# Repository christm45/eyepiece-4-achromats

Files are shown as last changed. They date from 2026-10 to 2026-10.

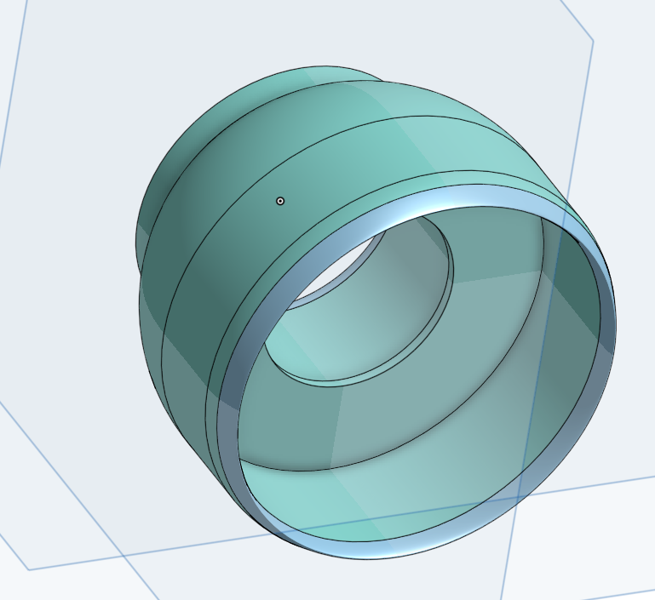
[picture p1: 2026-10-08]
top eye piece acceuil lentilles 30mm_3.png

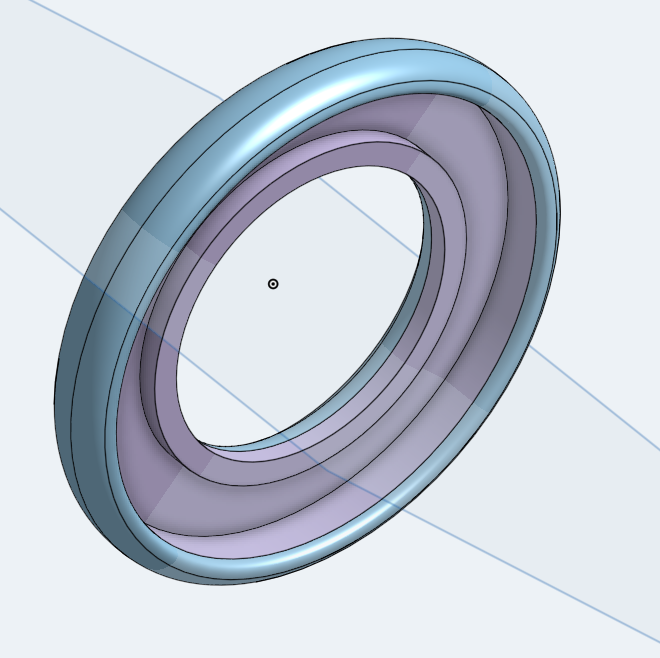
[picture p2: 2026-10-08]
top ring eye side 3d view.png

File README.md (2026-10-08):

# Oculaire 4 achromats / 4-achromat eyepiece

Oculaire de télescope imprimé en 3D, fait de 4 achromats de jumelles : une paire Ø40 mm côté focuser 2" et une paire Ø30 mm côté œil.
3D-printed telescope eyepiece built from 4 binocular achromats: a Ø40 mm pair on the 2" focuser side and a Ø30 mm pair on the eye side.

**Essayer en ligne / Try it online : https://christm45.github.io/eyepiece-4-achromats/**

Les pages 3D ont un bouton **FR / EN** (haut à droite de la vue). / The 3D pages have an **FR / EN** switch (top right of the view).

## Contenu / Contents

| Fichier / dossier | Rôle |
|---|---|
| `oculaire_3D.html` | Assemblage 3D (éclaté, coupe, rayons) + modèle optique du champ. Autonome : ouvrir dans un navigateur. |
| `banc_focale_3D.html`, `banc focale lentilles/` | Banc de mesure de la focale des achromats (STL, STEP, LISEZMOI, simulation 3D). |
| `stl_oculaire/` | Les 6 pièces imprimées de l'oculaire (STL). |
| `essais_oeilleton/` | Œilletons d'essai pour 24 / 20 / 17 / 14 mm de dégagement. |
| `build_oculaire.py` | Modèle CAO paramétrique (CadQuery). |
| `optics.js`, `test_optics.js` | Modèle optique paraxial (source unique de la page et des tests : `node test_optics.js`). |
| `mesure_focale.py` | Calcul de la focale à partir des lectures du banc. |
| `make_html.py`, `make_banc.py`, `mesh_export.py`, `export_stl.py`, `export_essais.py` | Régénération des pages, des maillages et des STL. |
| `vendor/` | three.js (licence MIT) intégré aux pages. |

## Précision : ce qui est mesuré, estimé, calculé

- **Lues sur les captures Onshape** (`*.png`) : Ø50,8 / Ø56 / Ø42,5 / Ø37 / profondeur 27 (base) ; Ø61 / Ø56,3 / Ø33 / Ø29 (coiffe) ; bague Ø50 / Ø44,3 / Ø32,5 / Ø28, hauteur 5,9.
- **Estimées, à ajuster** : épaisseurs des achromats (8 mm pour Ø40, 6 mm pour Ø30), longueur de la base, forme du dôme.
- **Focales : par défaut 160 / 110 mm = valeurs typiques de jumelles, PAS mesurées.** Mesurez les vôtres avec le banc, puis entrez-les dans la page : tous les chiffres se recalculent.
- **Modèle optique** : premier ordre, lentilles minces placées au milieu de leur épaisseur, ouvertures finies. Il donne la géométrie (vignettage, champ, dégagement, focale) mais **pas la netteté au bord** (astigmatisme, courbure de champ, coma, distorsion). Vérifié contre la formule de deux paires minces (F = F1·F2 / (F1 + F2 − d)).
- **Dégagement d'œil** : mesuré depuis la dernière surface de verre. **Plan de champ** : mesuré depuis la première surface de verre.
- Pupille de sortie prise à 4 mm et diaphragme de champ du fourreau 2" à Ø46 (valeurs nominales ; à adapter à votre fourreau).

Aucun résultat de ce dépôt n'a été validé sur le ciel : c'est un outil de conception, pas une garantie de performance.

## Licence / License

MIT : utilisation, copie, modification et partage libres (y compris commercial), en conservant la mention de copyright. Voir `LICENSE`. three.js (`vendor/`) reste sous sa propre licence MIT.
MIT: free to use, copy, modify and share (commercial use included), keeping the copyright notice. See `LICENSE`. three.js (`vendor/`) keeps its own MIT license.

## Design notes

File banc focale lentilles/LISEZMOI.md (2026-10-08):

# Banc de mesure de la focale des achromats

Pièces (STL, une impression chacune) : `1_rail_A`, `2_rail_B`, `3_chariot_lentille`, `4_chariot_ecran`, `5_support_source`.
`assemblage_banc.step` montre l'ensemble. Le rail fait 2 × 160 mm ; les deux moitiés s'emboîtent par une queue d'aronde (jeu 0,35 mm) :
graduation de 0 à 305 mm, un trait par mm (plus long tous les 5 et 10 mm), chiffres tous les 50 mm.

## Principe
Une source **lointaine** (au moins 2 m : fenêtre éloignée, LED au bout de la pièce, lampe) est imagée par la lentille sur un écran
(papier sulfurisé / calque) qui coulisse sur le rail. On lit où l'image est nette, puis :

    f = u·v / (u + v)

`u` = distance source → lentille au mètre ruban ; `v` = distance lentille → écran. Avec u = 3 m, sans correction l'erreur serait de 5 %
sur une focale de 160 mm : c'est pourquoi la formule est obligatoire.

## Montage
1. Imprimez les 5 pièces (chariots : posez-les sur leur face de glissement ouverte vers le bas avec supports, ou retournés ; vérifiez que le rail coulisse avant de l'utiliser, au besoin poncez ou changez `JEU`).
2. Emboîtez le rail B dans le rail A par la queue d'aronde. Posez le tout sur une table.
3. Chariot lentille : la lentille se pose dans le logement étagé **depuis l'avant (côté source)** ; elle s'appuie sur un épaulement :
   Ø50 → épaulement 1, Ø40 → épaulement 2, Ø30 → épaulement 3. Serrez-la par la tranche avec une vis **M3 en nylon** (2 trous M3 sur le dessus, à tarauder).
   Orientez l'achromat comme il l'était dans les jumelles (côté objet vers la source) ; la focale ne dépend pas du sens, mais l'image est plus nette ainsi.
4. Chariot écran : glissez une bande de papier sulfurisé dans la fente du haut (c'est le plan de mesure).
5. Support source (`5_support_source`) : la **LED 5 mm est sur l'axe optique** (z = 52 mm, même hauteur que la lentille ; elle était à 38 mm dans une version précédente). Insérez la LED **par l'arrière**, collerette contre l'épaulement (les fils sortent par la rainure du bas). Devant la pointe, dans la fente de 1,1 mm : un **masque** en papier alu (trou d'épingle ~0,5 mm percé à l'aiguille, ou petite croix). La sortie est évasée : la lumière diverge après le trou.
   Alimentation : 5 V USB + résistance ~150 Ω (LED blanche, ~12 mA), ou pile 3 V + ~47 Ω. Une LED nue (Ø5) marche aussi (image de ~0,3 mm à 3 m) mais le masque donne une mise au point plus précise.
   Posez le support sur la table, à 2 m ou plus de la lentille, face au rail, LED à la même hauteur que l'axe du chariot lentille. La page 3D simule la LED, le masque, le faisceau et la taille de l'image du masque sur l'écran.

## Lecture
Chaque chariot a une **fenêtre de lecture** de 10 × 23 mm au-dessus de la voie graduée, avec un **fil repère** de 0,8 mm : on lit le trait qui est sous le fil ; les chiffres sont gravés tous les 10 mm et visibles dans la fenêtre (traits tous les mm, plus longs à 5 et 10 mm). Regardez de dessus, à la verticale, pour éviter la parallaxe.
- Chariot lentille : le fil repère est 11,5 / 8,5 / 5,5 mm derrière la face arrière de la lentille (Ø50 / Ø40 / Ø30).
- Chariot écran : le fil repère est 8,0 mm derrière le plan du papier.
Notez la lecture du chariot lentille, déplacez l'écran jusqu'à l'image la plus nette (petit point lumineux), notez sa lecture, puis :

    python mesure_focale.py 40 60 225 3000 8

(Ø40, lectures 60 et 225, source à 3000 mm, épaisseur de la lentille 8 mm). Le script donne BFD, v et f.

## Précision et pièges
- Lecture à ±0,5 mm sur chaque trait : f à ±1 mm. Le plan principal d'un achromat épais est supposé au milieu de son épaisseur : jusqu'à ~2 mm d'écart possible.
- Pour une meilleure précision : mesurez **deux fois**, la lentille retournée, et prenez la moyenne.
- Un achromat de jumelle est corrigé pour une source lointaine et un faisceau étroit : travaillez à pleine ouverture mais cherchez l'image la plus petite, pas la plus lumineuse.
- Des focales jusqu'à ~280 mm tiennent sur le rail (305 mm). Au-delà, rallongez en ajoutant un segment.
- Pour une **paire** (les deux achromats face à face), mesurez-la montée comme dans l'oculaire (écart entre les lentilles = celui de l'oculaire) : sa focale est ≈ f/2.
- Les trois jeux et dimensions sont dans `build_banc.py` (`JEU`, `RAIL_SEG`, `STEPS`) si votre imprimante demande un autre réglage.

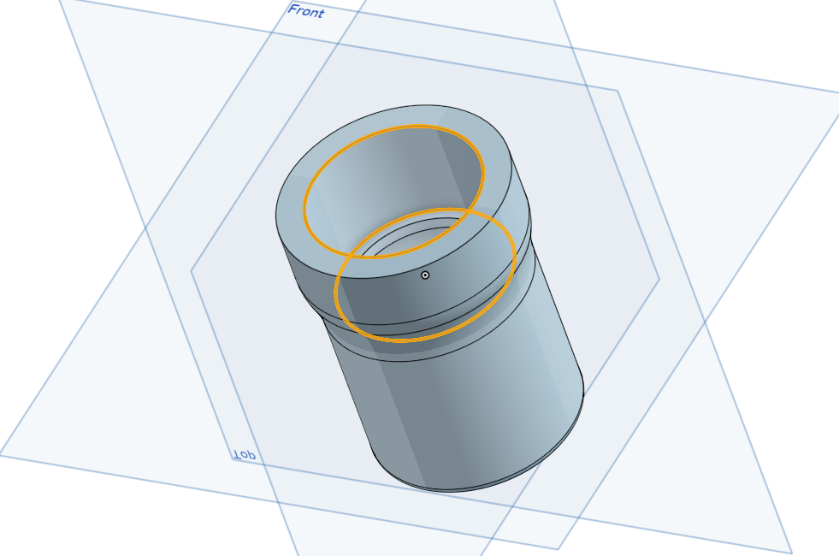
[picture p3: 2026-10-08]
base basse cavité lentilles 40mm coté focuser 2 inch_3_27mm profondeur acceuil lentilles 40mm.png

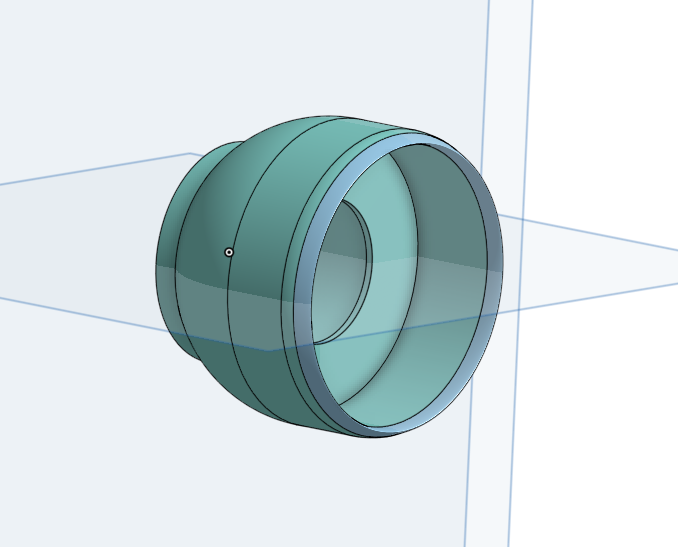
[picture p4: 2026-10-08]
top eye piece acceuil lentilles 30mm.png

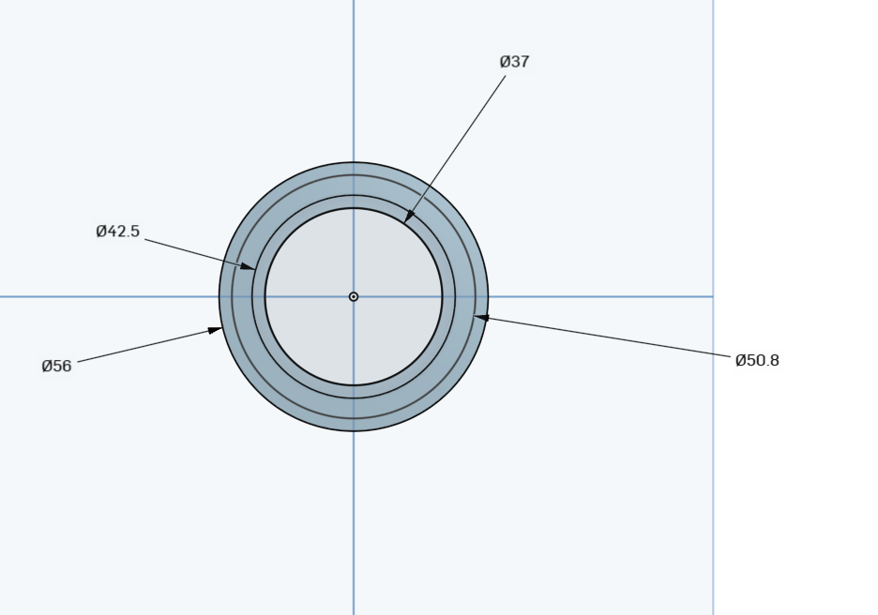
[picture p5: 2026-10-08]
base basse cavité lentilles 40mm coté focuser 2 inch.png

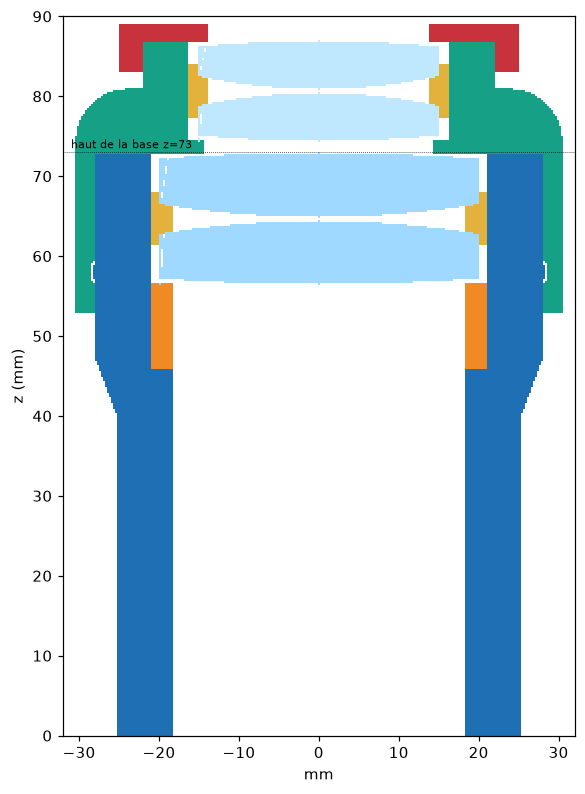
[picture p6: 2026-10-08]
coupe.png

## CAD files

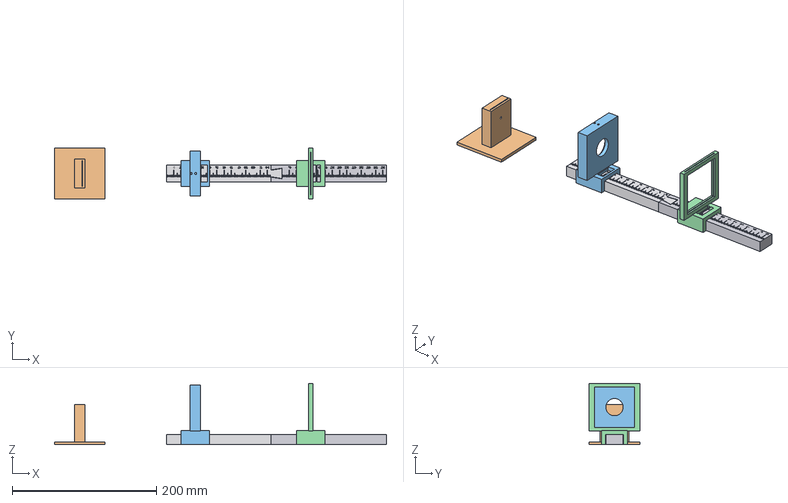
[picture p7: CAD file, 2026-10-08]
banc focale lentilles/assemblage_banc.step
460.0 x 70.0 x 85.0 mm
rail_A
rail_B
chariot_lentille
chariot_ecran
support_source

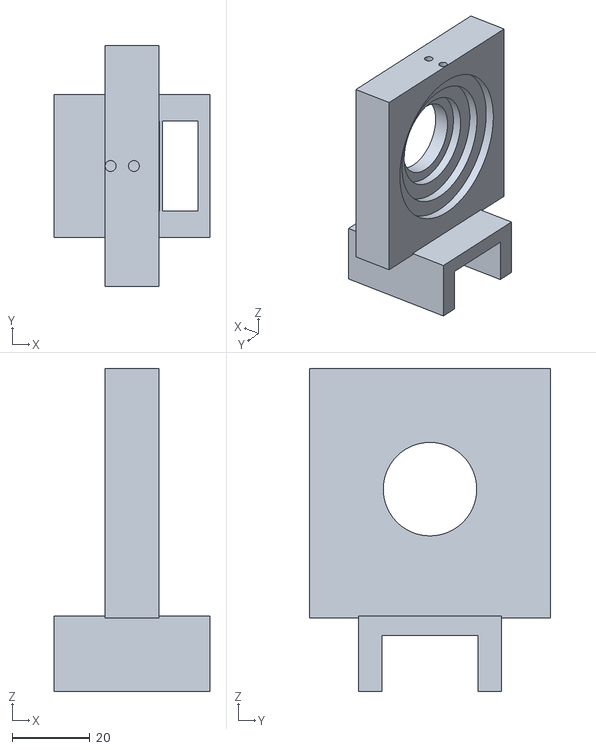
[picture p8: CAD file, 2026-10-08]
banc focale lentilles/3_chariot_lentille.stl
40.0 x 62.0 x 83.0

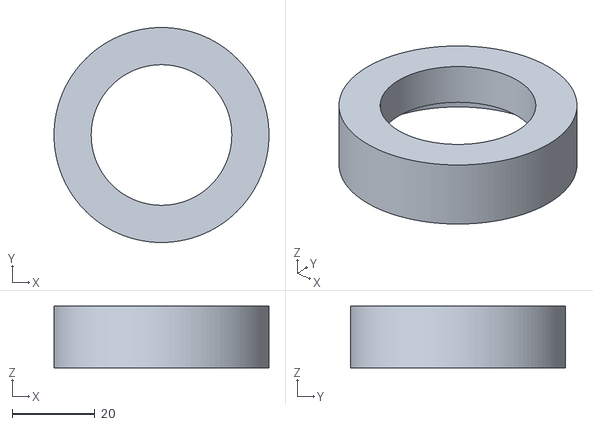
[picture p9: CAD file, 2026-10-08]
essais_oeilleton/oeilleton_degagement_14mm.stl
52.0 x 52.0 x 14.9

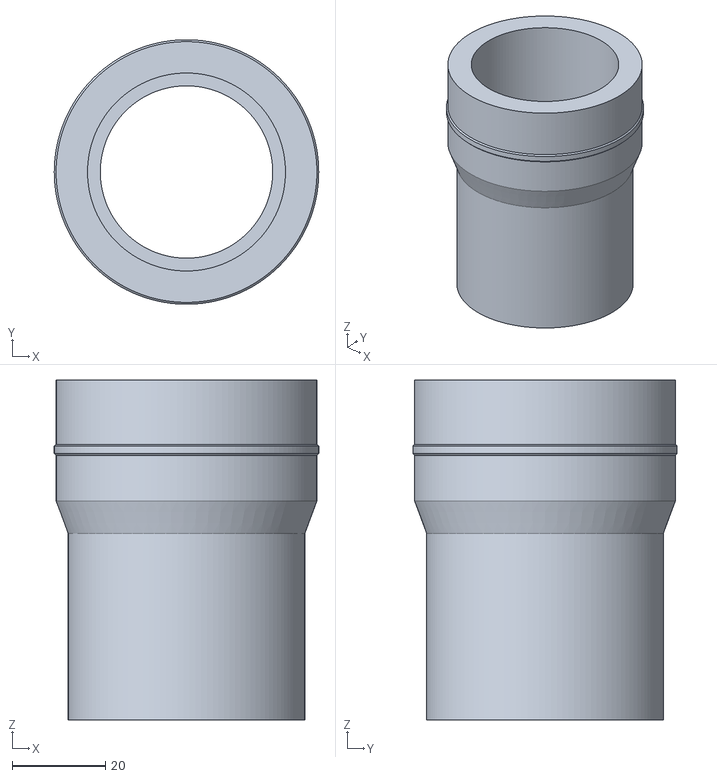
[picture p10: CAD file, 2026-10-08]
stl_oculaire/1_base_basse_D50_8_poche_D42_5_x_27.stl
56.8 x 56.8 x 73.0

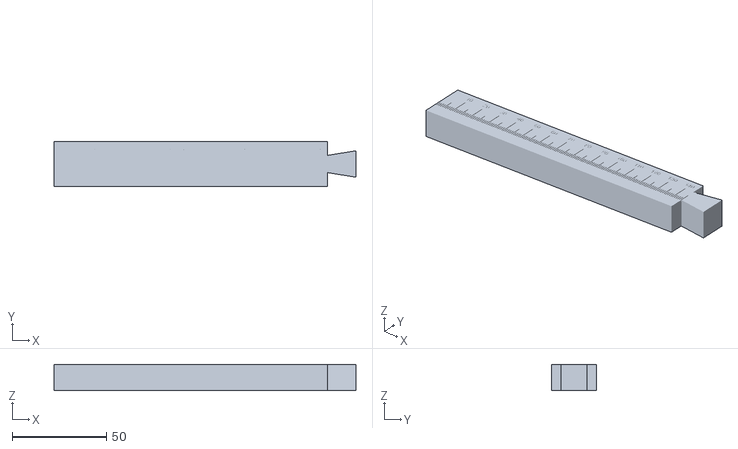
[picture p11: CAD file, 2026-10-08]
banc focale lentilles/1_rail_A.stl
160.0 x 24.0 x 14.0

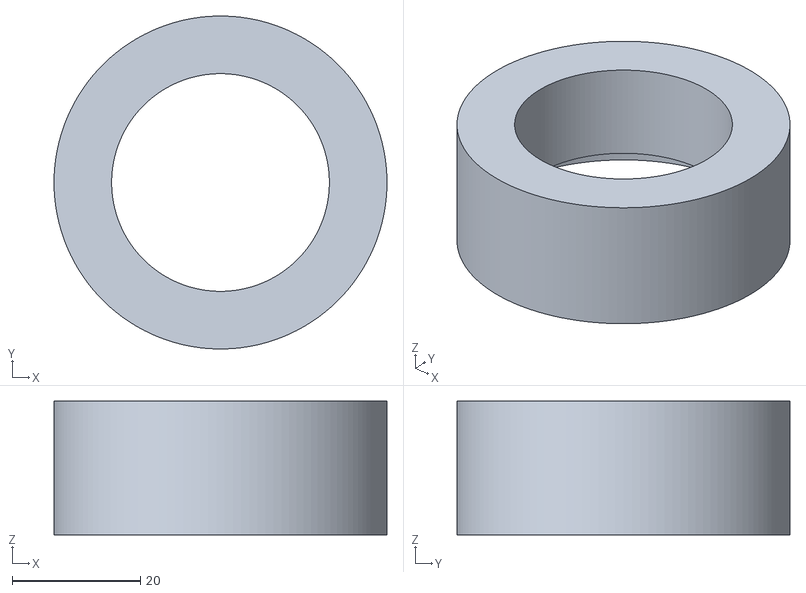
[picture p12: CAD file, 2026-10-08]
essais_oeilleton/oeilleton_degagement_20mm.stl
52.0 x 52.0 x 20.9

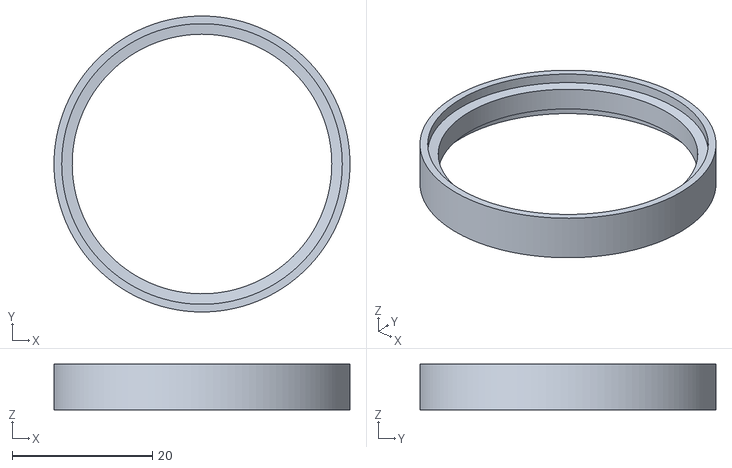
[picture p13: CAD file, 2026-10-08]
stl_oculaire/5_bague_despacement_paire_D40.stl
42.2 x 42.2 x 6.50

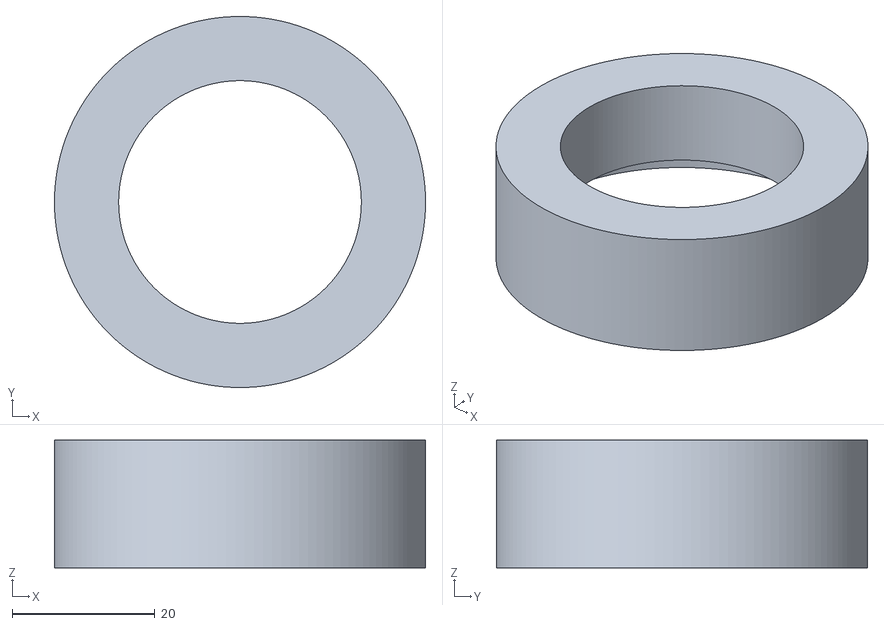
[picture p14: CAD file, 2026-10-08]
essais_oeilleton/oeilleton_degagement_17mm.stl
52.0 x 52.0 x 17.9

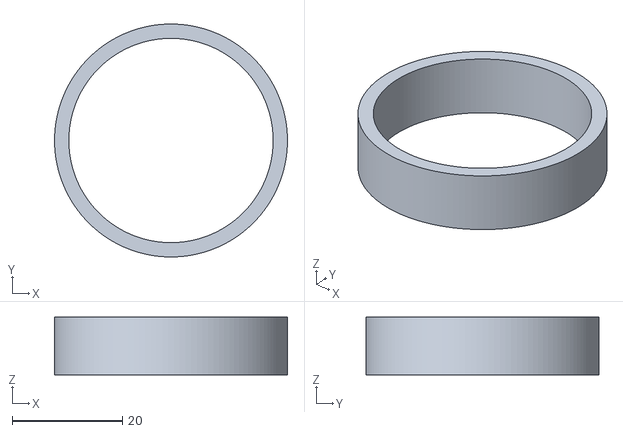
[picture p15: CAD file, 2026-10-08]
stl_oculaire/2_cale_sous_la_paire_D40.stl
42.2 x 42.2 x 10.5

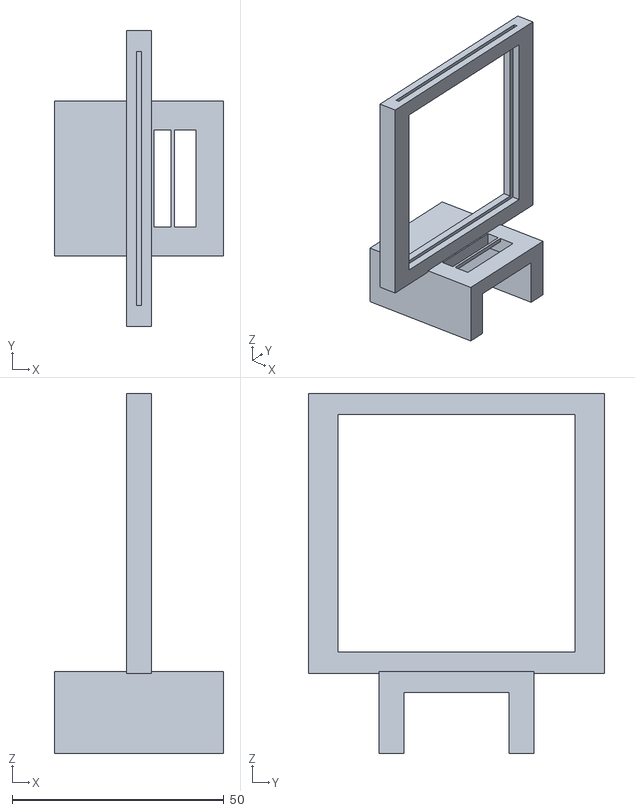
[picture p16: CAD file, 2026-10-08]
banc focale lentilles/4_chariot_ecran.stl
40.0 x 70.0 x 85.0

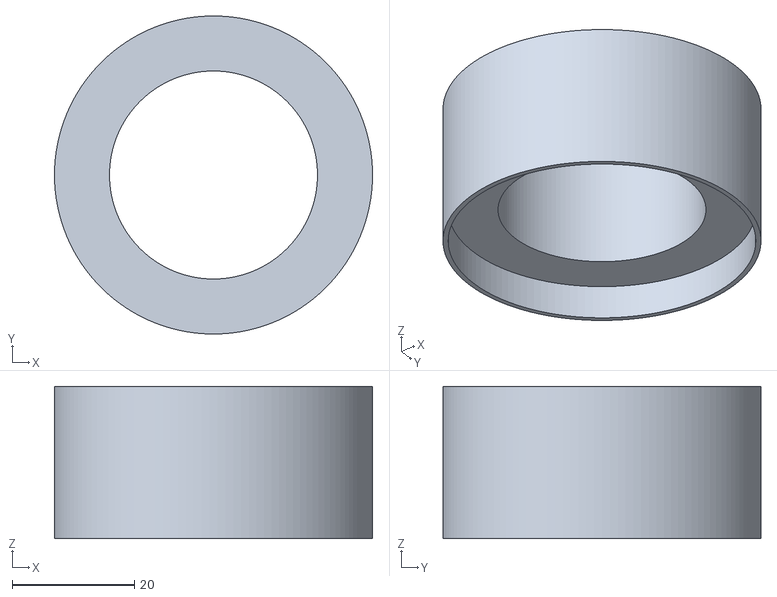
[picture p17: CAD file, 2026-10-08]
essais_oeilleton/oeilleton_degagement_24mm.stl
52.0 x 52.0 x 24.9

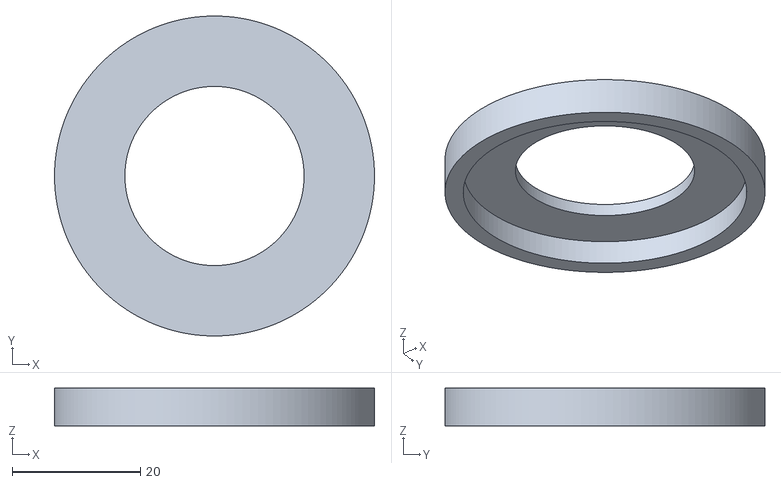
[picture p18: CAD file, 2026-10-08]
stl_oculaire/4_bague_de_serrage_cote_oeil.stl
50.0 x 50.0 x 5.90

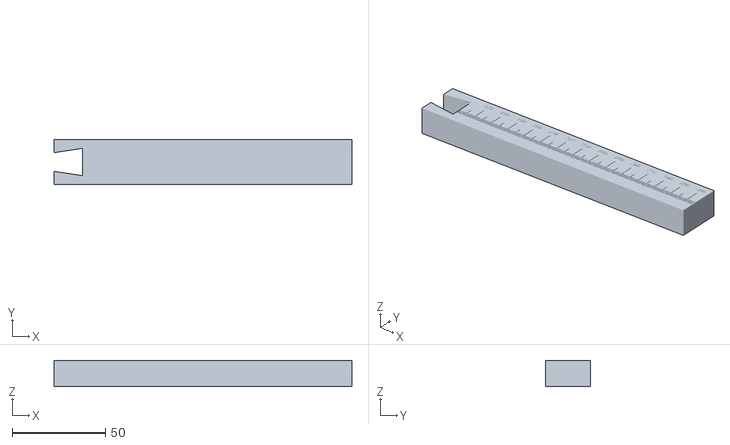
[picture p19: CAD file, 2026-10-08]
banc focale lentilles/2_rail_B.stl
160.0 x 24.0 x 14.0

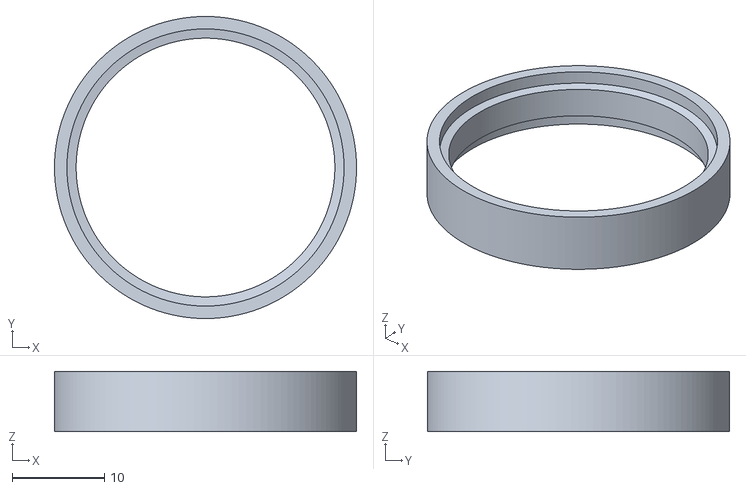
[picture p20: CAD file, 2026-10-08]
stl_oculaire/6_bague_despacement_paire_D30.stl
32.7 x 32.7 x 6.50

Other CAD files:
banc focale lentilles/5_support_source.stl
stl_oculaire/3_coiffe_oeil_poche_D33.stl

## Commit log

2026-10-08 Oculaire 4 achromats : modeles CAO, pages 3D FR/EN, calculs optiques
    [1_rail_A.stl, 2_rail_B.stl, 3_chariot_lentille.stl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]
2026-10-08 Audit : degagement d'oeil depuis la derniere surface, textes corriges, STL de l'oculaire, vendor/ integre, README
    [1_base_basse_D50_8_poche_D42_5_x_27.stl, 2_cale_sous_la_paire_D40.stl, 3_coiffe_oeil_poche_D33.stl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]
2026-10-08 README : lien vers la page en ligne
2026-10-08 Banc de focale : vraie fenetre de lecture (10x23 mm) + fil repere sur chaque chariot, chiffres tous les 10 mm sur le rail ; textes FR/EN et LISEZMOI
    [1_rail_A.stl, 2_rail_B.stl, 3_chariot_lentille.stl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]
2026-10-08 Banc : simulation de la source LED + masque (LED, trou d'epingle/croix, faisceau, image sur l'ecran), LED remise sur l'axe optique (z 38 -> 52), sortie evasee, rainure des fils, vue source ; LISEZMOI
2026-10-08 Banc : reglette volante a hauteur de l'axe optique montrant la VRAIE focale (curseur) + repere orange de la focale mesuree + distance image v
